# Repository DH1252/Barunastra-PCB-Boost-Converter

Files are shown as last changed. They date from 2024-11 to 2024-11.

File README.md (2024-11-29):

# Barunastra-PCB-Boost-Converter

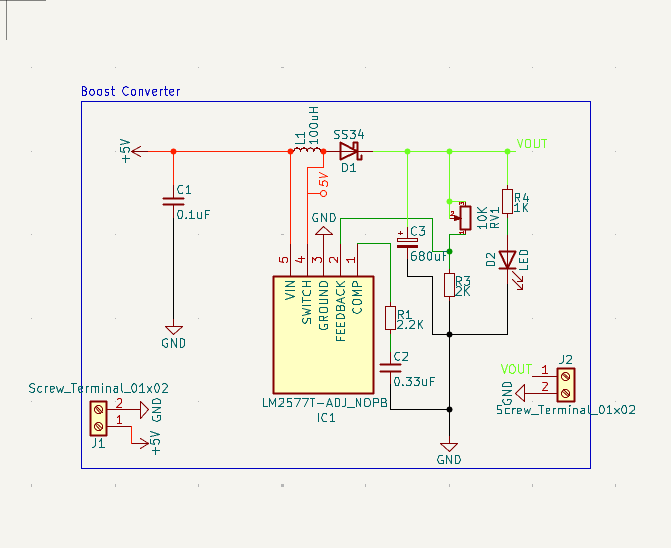
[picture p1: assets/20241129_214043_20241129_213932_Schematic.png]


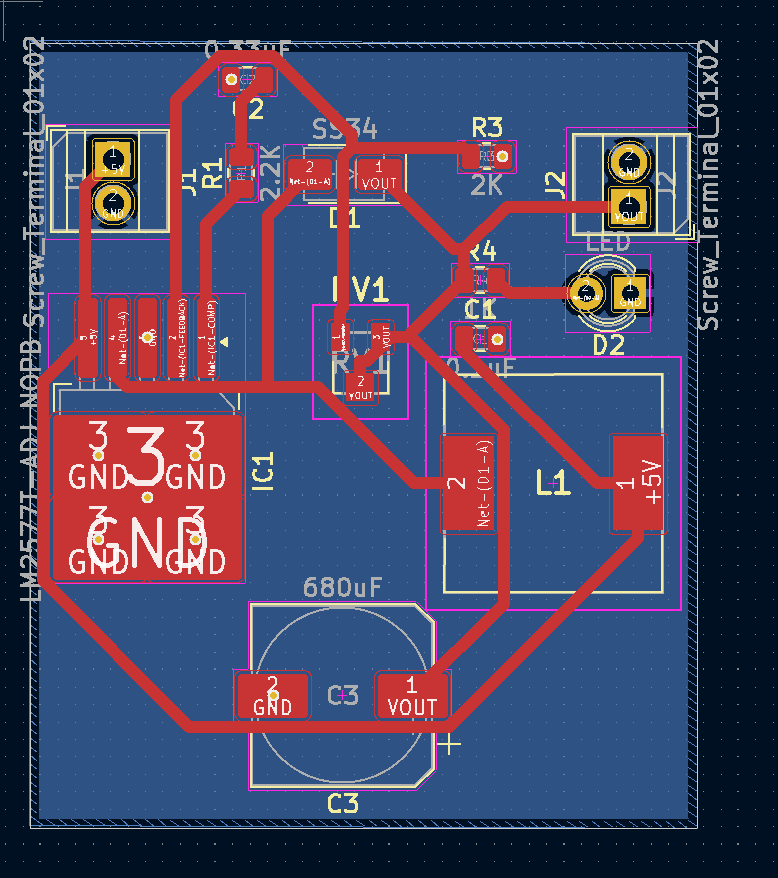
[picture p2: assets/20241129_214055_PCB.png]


This is an adjustable boost converter based on the LM2577 IC that can handle upto 2A

It features an adjustable output voltage, a output smoothing capacitor, and a LED indicator

It uses two screw terminals for input and output

The PCB is two layers and a track width of 0.7 mm to handle 2 Amps

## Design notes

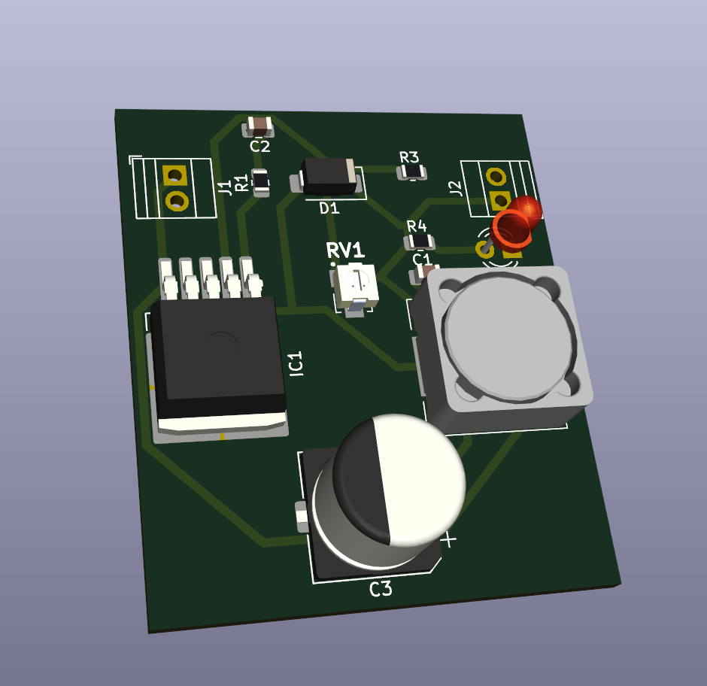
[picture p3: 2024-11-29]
assets/3D.png

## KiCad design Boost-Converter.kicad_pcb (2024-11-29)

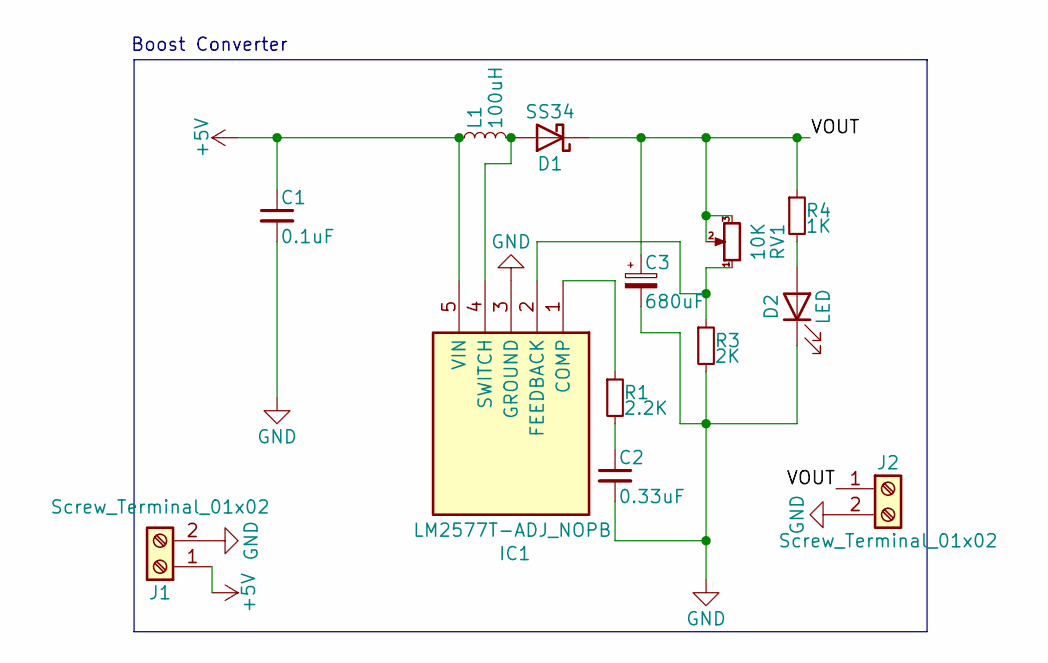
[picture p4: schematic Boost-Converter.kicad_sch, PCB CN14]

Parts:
C1: 0.1uF; C_0805_2012Metric
C2: 0.33uF; C_0805_2012Metric
C3: 680uF; CP_Elec_10x10
D1: SS34; D_SMA
D2: LED; LED_D3.0mm
IC1: LM2577T-ADJ_NOPB; TO-263-5_TabPin3; Manufacturer_Part_Number LM2577T-ADJ/NOPB; Mouser Part Number 926-LM2577T-ADJ/NOPB
J1, J2: Screw_Terminal_01x02; TerminalBlock_Xinya_XY308-2.54-2P_1x02_P2.54mm_Horizontal
L1: 100uH; SRR1260101M
R1: 2.2K; R_0805_2012Metric
R3: 2K; R_0805_2012Metric
R4: 1K; R_0805_2012Metric
RV1: 10K; 3313J1503E

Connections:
+5V: C1.1, IC1.5 (VIN), J1.1, L1.1
/VOUT: C3.1, D1.1 (K), J2.1, R4.1, RV1.2, RV1.3
GND: C1.2, C2.2, C3.2, D2.1 (K), IC1.3 (GROUND), J1.2, J2.2, R3.2
unnamed: C2.1, R1.2
unnamed: D1.2 (A), IC1.4 (SWITCH), L1.2
unnamed: D2.2 (A), R4.2
unnamed: IC1.1 (COMP), R1.1
unnamed: IC1.2 (FEEDBACK), R3.1, RV1.1

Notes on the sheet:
Boost Converter

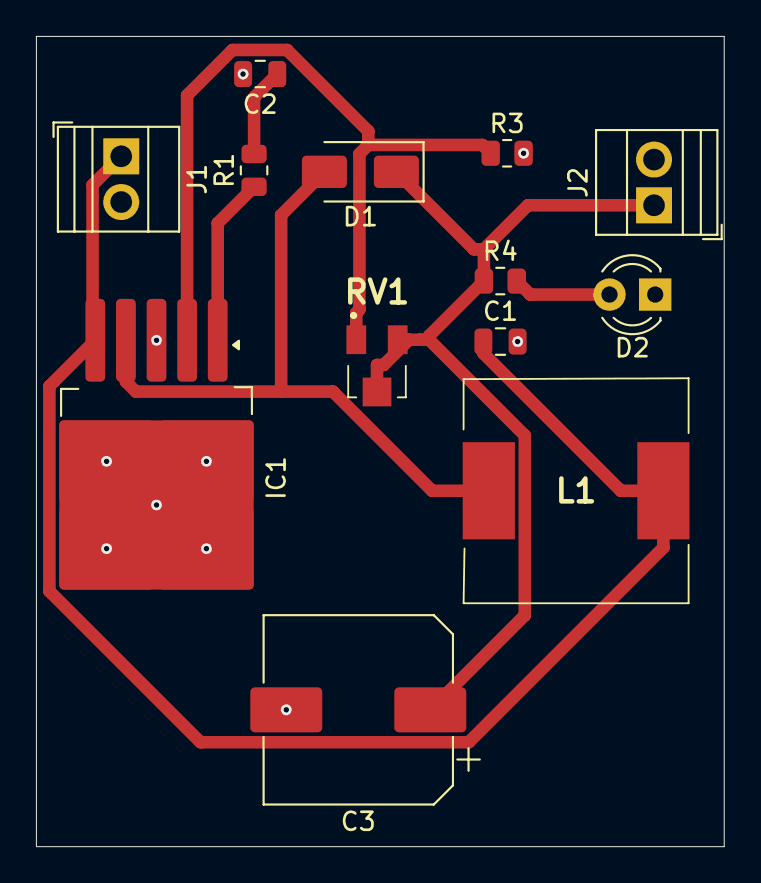
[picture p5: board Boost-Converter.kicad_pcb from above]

Board: 2 copper layers, 38.2 x 45.0 mm, 13 parts (0 on the bottom side), 8 nets.
